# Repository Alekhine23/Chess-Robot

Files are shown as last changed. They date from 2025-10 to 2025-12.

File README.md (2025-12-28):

Chess Engine download:
- Stockfish - (https://stockfishchess.org/download/)

Arduino libraries:
- VarSpeedServo - (https://github.com/netlabtoolkit/VarSpeedServo)
- AccelStepper - (install from Library Manager in Arduino IDE)

Python libraries:
- pip install chess
- pip install pyserial 
- pip install stockfish

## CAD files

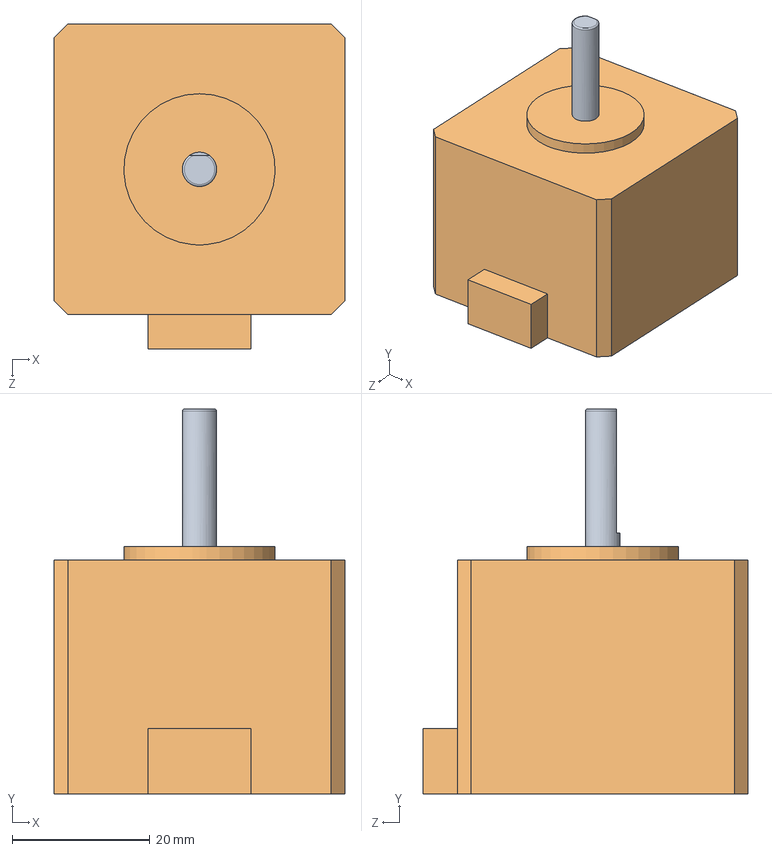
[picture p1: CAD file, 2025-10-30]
Solidworks Model/Steppers/pitch motor/pitch motor.SLDASM
42.3 x 56.0 x 47.3 mm
pitch motor base
pitch motor shaft

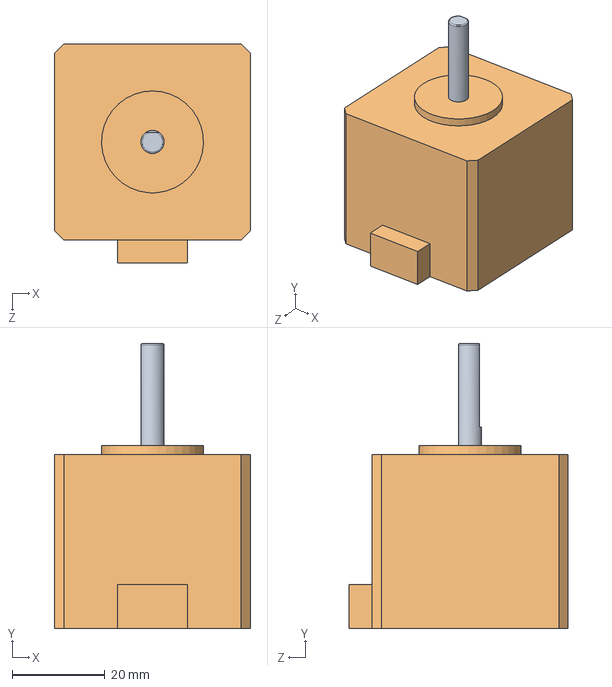
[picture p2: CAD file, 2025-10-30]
Solidworks Model/Steppers/yaw motor/yaw motor.SLDASM
42.3 x 61.5 x 47.3 mm
yaw motor base
yaw motor shaft

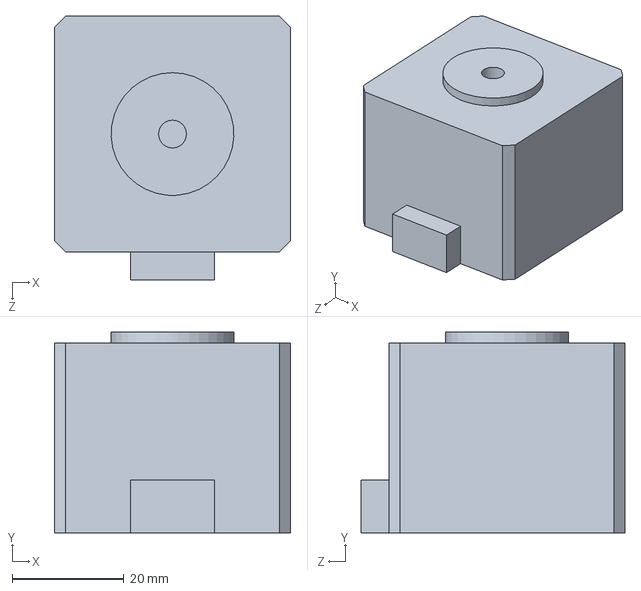
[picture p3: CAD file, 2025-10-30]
Solidworks Model/Steppers/pitch motor/pitch motor base.SLDPRT
42.3 x 36.0 x 47.3 mm

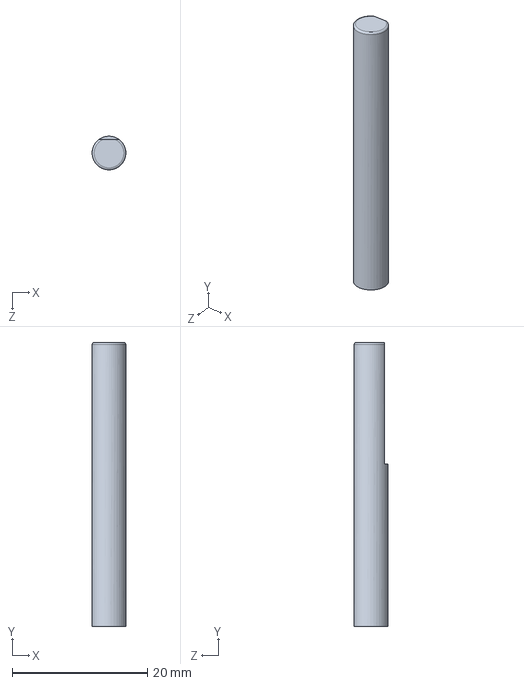
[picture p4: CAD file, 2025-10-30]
Solidworks Model/Steppers/yaw motor/yaw motor shaft.SLDPRT
4.99 x 42.0 x 5.00 mm

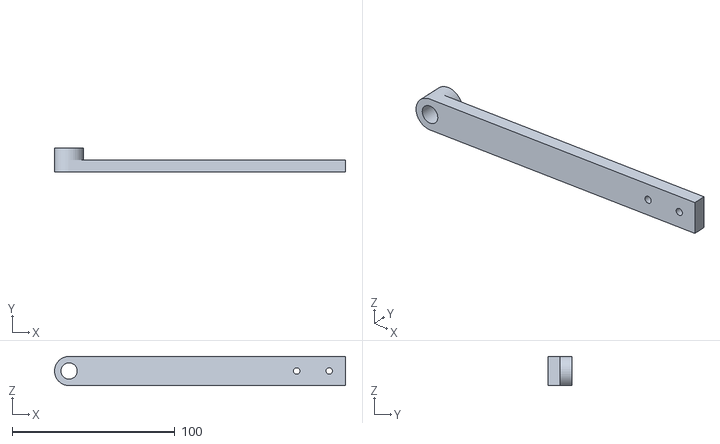
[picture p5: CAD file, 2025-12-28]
STLs and dxfs/elbow wrist link 2B rev1.STL
179.0 x 15.0 x 18.0

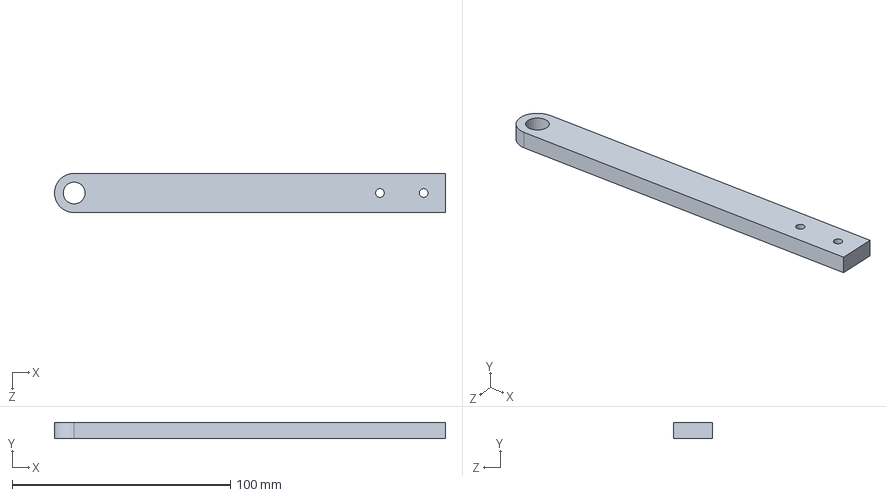
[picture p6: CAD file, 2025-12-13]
Solidworks Model/elbow wrist link 2A rev1.SLDPRT
179.0 x 7.50 x 18.0 mm

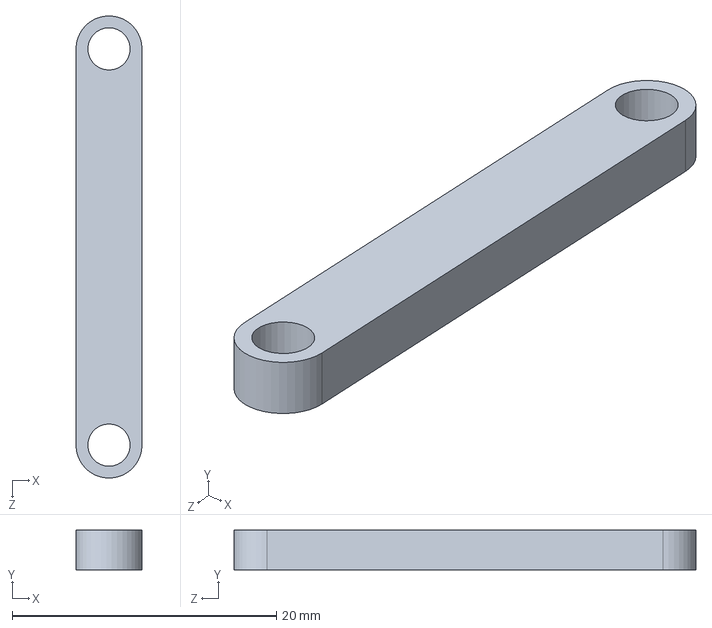
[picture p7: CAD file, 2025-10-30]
Solidworks Model/End Effector/link A.SLDPRT
5.00 x 3.00 x 35.0 mm

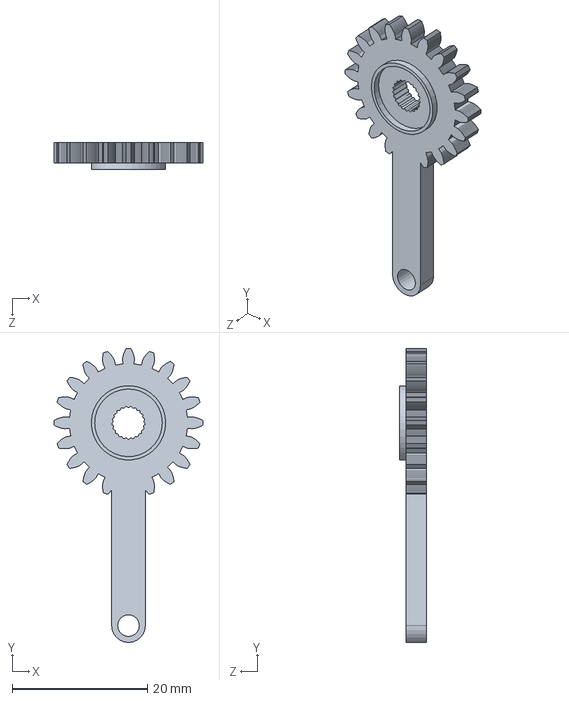
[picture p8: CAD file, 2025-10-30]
Solidworks Model/End Effector/splined grabber.SLDPRT
22.0 x 43.5 x 4.00 mm

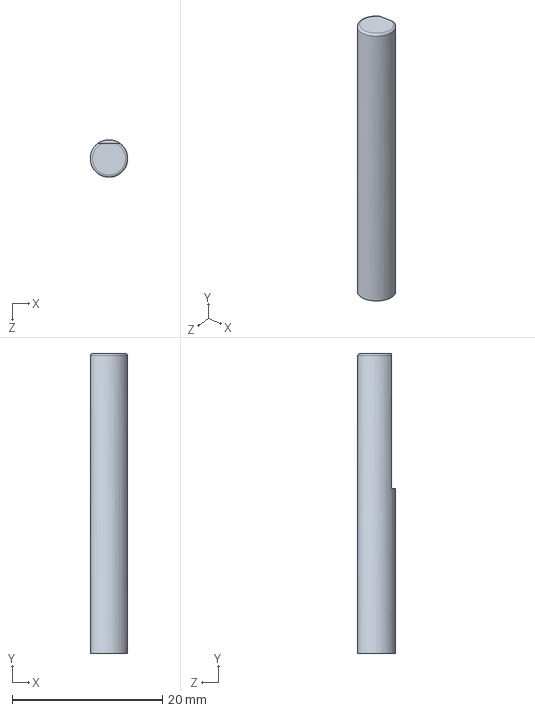
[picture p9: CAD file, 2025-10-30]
Solidworks Model/Steppers/pitch motor/pitch motor shaft.SLDPRT
5.00 x 40.0 x 5.00 mm

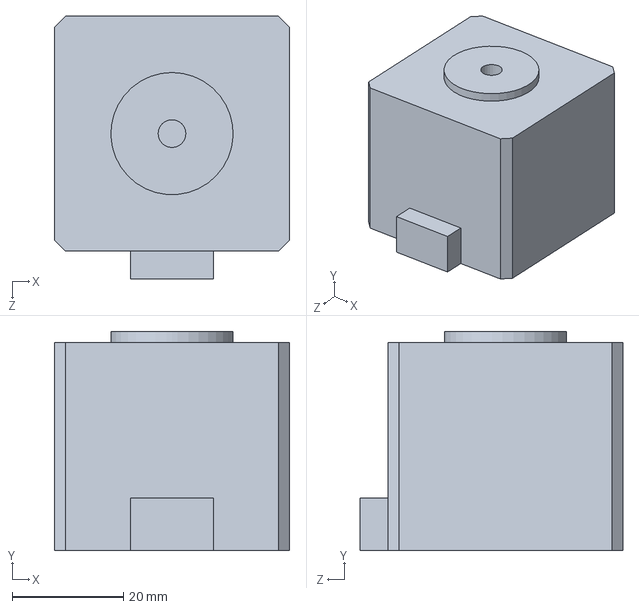
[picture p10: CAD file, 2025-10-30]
Solidworks Model/Steppers/yaw motor/yaw motor base.SLDPRT
42.3 x 39.5 x 47.3 mm

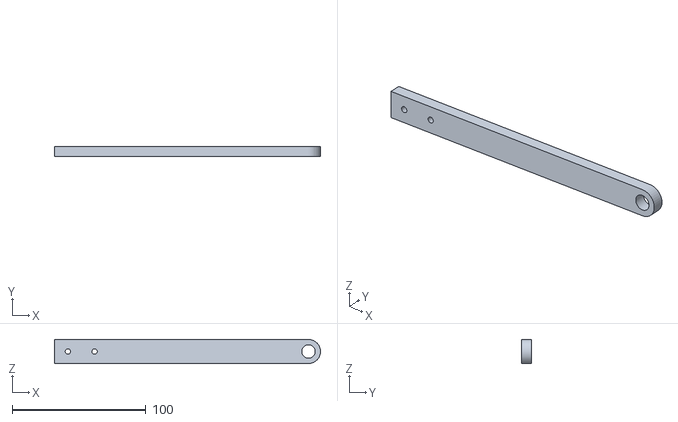
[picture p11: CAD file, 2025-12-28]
STLs and dxfs/elbow wrist link 1A rev1.STL
199.0 x 7.50 x 18.0

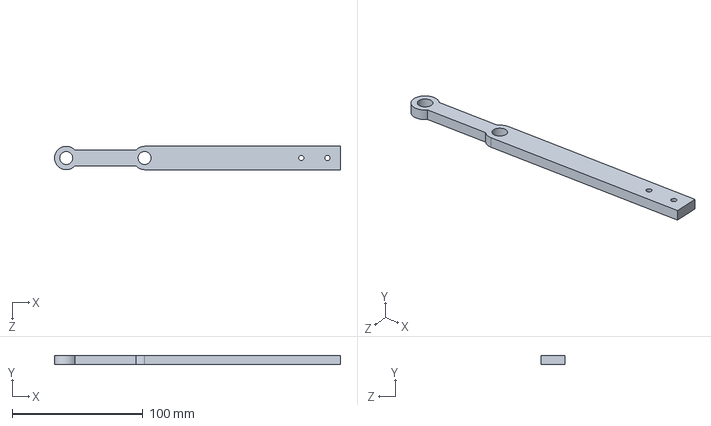
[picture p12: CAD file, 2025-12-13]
Solidworks Model/elbow wrist link 1B rev1.SLDPRT
219.0 x 7.00 x 18.0 mm

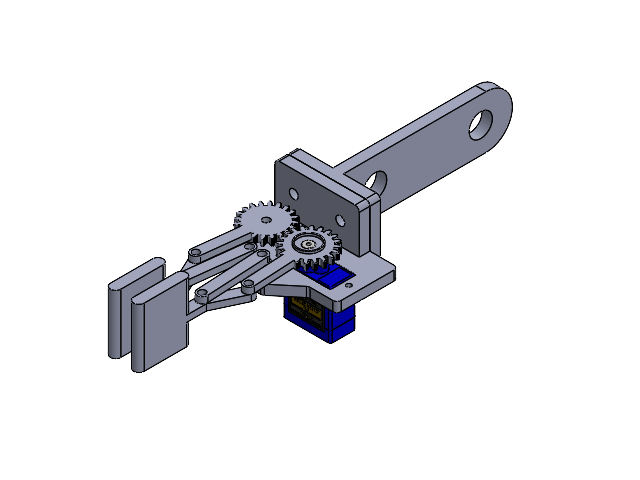
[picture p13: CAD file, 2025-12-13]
Solidworks Model/End Effector/end effector assembly - thicker arm test.SLDASM
chassis
chassis holder
servo motor
splined grabber
unsplined grabber
link A x 2
link B
link C

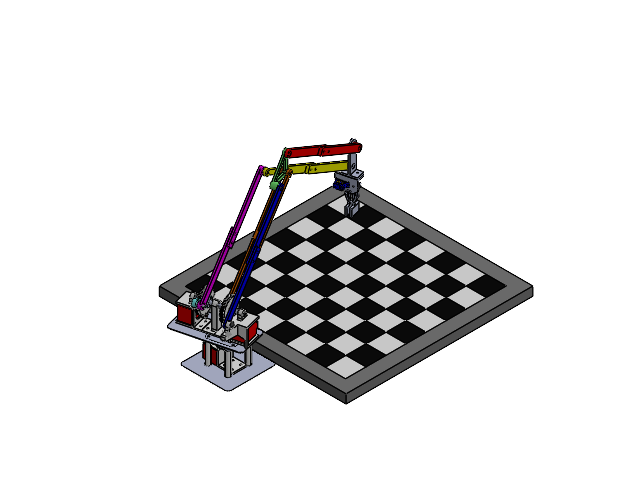
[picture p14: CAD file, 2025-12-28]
Solidworks Model/Full Assembly.SLDASM
bottom base plate
base standoff x 4
yaw motor mount
yaw motor base
yaw motor shaft
yaw motor drive gear
lazy susan bearing x 2
top base plate
pitch motor mount A
pitch motor mount B
shoulder middle axle support
5dia 64 long shaft
5dia 59 long shaft
pitch motor drive gear x 2
pitch motor base x 2
pitch motor shaft x 2
pitch motor driven gear x 2
shoulder axle shaft collar x 4
elbow triangle link
shoulder elbow link 1A x 2
shoulder elbow link 1B x 2
shoulder link 3
shoulder elbow link 4A
shoulder elbow link 4B
5dia 28 long shaft
shoulder elbow link 2A
shoulder elbow link 2B
board
yaw motor driven gear
5dia 15 long shaft x 2
5dia 22.5 long shaft
5dia 25 long shaft
elbow wrist link 1A rev1
elbow wrist link 1B rev1
chassis
chassis holder
servo motor
splined grabber
unsplined grabber
link A x 2
link B
link C
elbow wrist link 2A rev1
elbow wrist link 2B rev1

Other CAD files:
Solidworks Model/End Effector/end effector assembly.SLDASM
STLs and dxfs/elbow wrist link 2A rev1.STL
Solidworks Model/elbow wrist link 2B rev1.SLDPRT
STLs and dxfs/elbow wrist link 1B rev1.STL
STLs and dxfs/base standoff.STL
STLs and dxfs/bottom base plate.DXF
STLs and dxfs/chassis holder.STL
STLs and dxfs/chassis.STL
STLs and dxfs/elbow triangle link.STL
STLs and dxfs/link A.STL
STLs and dxfs/link B.STL
STLs and dxfs/link C.STL
STLs and dxfs/pitch motor drive gear.STL
STLs and dxfs/pitch motor driven gear.STL
STLs and dxfs/pitch motor mount A.STL
STLs and dxfs/pitch motor mount B.STL
STLs and dxfs/shoulder elbow link 1A.STL
STLs and dxfs/shoulder elbow link 1B.STL
STLs and dxfs/shoulder elbow link 2A.STL
STLs and dxfs/shoulder elbow link 2B.STL
STLs and dxfs/shoulder elbow link 4A.STL
STLs and dxfs/shoulder elbow link 4B.STL
STLs and dxfs/shoulder link 3.STL
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

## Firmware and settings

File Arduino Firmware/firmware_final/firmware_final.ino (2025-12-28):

#include <AccelStepper.h>
#include <MultiStepper.h>

#include <VarSpeedServo.h>

const int signal_servo = 12;
const int stepPinRight = 5;
const int dirPinRight = 6;
const int stepPinLeft = 3;
const int dirPinLeft = 4;
const int stepPinBase = 7;
const int dirPinBase = 8;
const int MS1 = 9;
const int MS2 = 10;
const int MS3 = 11;

int command = 0;
int angle;
int speed;
int expectedBytes;

const float degPerStep = 0.9;
int gearRatio = 5;

AccelStepper stepperRight(AccelStepper::DRIVER, stepPinRight, dirPinRight);
AccelStepper stepperLeft(AccelStepper::DRIVER, stepPinLeft, dirPinLeft);
AccelStepper stepperBase(AccelStepper::DRIVER, stepPinBase, dirPinBase);

VarSpeedServo myServo;

void setup() {
  pinMode(stepPinRight, OUTPUT);
  pinMode(dirPinRight, OUTPUT);
  pinMode(stepPinLeft, OUTPUT);
  pinMode(dirPinLeft, OUTPUT);
  pinMode(stepPinBase, OUTPUT);
  pinMode(dirPinBase, OUTPUT);

  pinMode(MS1, OUTPUT);
  pinMode(MS2, OUTPUT);
  pinMode(MS3, OUTPUT);
  digitalWrite(MS1, HIGH);
  digitalWrite(MS2, LOW);
  digitalWrite(MS3, LOW);

  Serial.begin(9600);
  myServo.attach(signal_servo);
  myServo.slowmove(95, 10);
  delay(1000);

  stepperRight.setMaxSpeed(100);
  stepperRight.setAcceleration(100);

  stepperLeft.setMaxSpeed(100);
  stepperLeft.setAcceleration(100);

  stepperBase.setMaxSpeed(100);
  stepperBase.setAcceleration(100);
}

void loop() {
   
  if (Serial.available() > 0) {
    command = Serial.read();

    switch (command) {
      case (1):
        expectedBytes = 2;
        break;
      case (2):
        expectedBytes = 6;
        break;
    }

    unsigned long startTime = millis();
    while (Serial.available() < expectedBytes) {
      if (millis() - startTime > 1000) {
        return;
      }
    }

    switch (command) {
      case (1):
        angle = Serial.read();
        speed = Serial.read();
        myServo.slowmove(angle, speed);

        while(myServo.isMoving()) {
        delay(10);
        }
        delay(100);
        break;

      case (2):
        int angleRight = Serial.read();
        int dirRight = Serial.read();
        int angleLeft = Serial.read();
        int dirLeft = Serial.read();
        int angleBase = Serial.read();
        int dirBase = Serial.read();

        stepperRight.setPinsInverted(dirRight == 0, false, false);
        stepperLeft.setPinsInverted(dirLeft == 0, false, false);
        stepperBase.setPinsInverted(dirBase == 0, false, false);

        int stepsRight = round((angleRight * gearRatio)/degPerStep);
        int stepsLeft = round((angleLeft * gearRatio)/degPerStep);
        int stepsBase = round((angleBase * gearRatio)/degPerStep);

        stepperRight.move(stepsRight);
        stepperLeft.move(stepsLeft);
        stepperBase.move(stepsBase);

        while (stepperRight.distanceToGo() != 0 || stepperLeft.distanceToGo() != 0 || stepperBase.distanceToGo() != 0) {
          stepperRight.run();
          stepperLeft.run();
          stepperBase.run();
          }
        break;
      
      default:
        break;
    }
  }
}

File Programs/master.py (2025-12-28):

from stockfish import Stockfish                 #used to get engine recommended moves
import chess                                    #used for game state tracking (draw, checkmate, captures, etc.)
import math
import serial
import time
import numpy as np

#SERIAL COMMUNICATION
arduino = serial.Serial(port='COM5', baudrate=9600)
time.sleep(2)
arduino.reset_input_buffer()

#CONSTANTS
square_length = 50
margin = 33

y_dist_base_to_board = 70
z_dist_board_to_base = 132.15

arm_length = 300
TCP_to_grab = 104

y_vals = [] #ranks 1 through 8
for i in range(7, -1 , -1):
    y_vals.append(int(margin + i*square_length + square_length/2 + y_dist_base_to_board))

x_vals_half = [] #files a through h
for i in range(3, -1, -1):
    print(i)
    x_vals_half.append(int((i*square_length) + (square_length/2)))
x_vals = x_vals_half
for i in x_vals_half[::-1]:
    x_vals.append(int(-i))

piece_heights = {"pawn": "47.1", "rook": "52.6", "knight": "60.5", "bishop": "68.4", "king": "91.3", "queen": "81.7"}
poised_gripper_heights = {"pawn": 151.1, "rook": 156.6, "knight": 164.5, "bishop": 172.4, "king": 195.3, "queen": 185.7}
close_angles = {"pawn": 95, "rook": 95, "bishop": 95, "knight": 95, "king": 95, "queen": 95}

servo_speed = 10
safe_angle = 95
open_angle = 120

#INITIALIZATION
zero_angles = [0, 0, 0]
capture_angles = [30, 45, 50] #Arbitrary; can dump anywhere on the side, adjust per user setup
position = []
board = chess.Board()

piece_map = {
    chess.PAWN: "pawn",
    chess.ROOK: "rook", 
    chess.KNIGHT: "knight",
    chess.BISHOP: "bishop",
    chess.QUEEN: "queen",
    chess.KING: "king"
}

stockfish = Stockfish(path="/Users/ebabb/Documents/Chess_Robot/stockfish.exe")

#FUNCTIONS
def get_angles(square, piece, is_poised):
    file = int(ord(square[0]) - ord('a'))
    rank = int(square[1]) - 1
    x = x_vals[file]
    y = y_vals[rank]
    if is_poised==0:
        z = float(piece_heights[f"{piece}"]) + TCP_to_grab - z_dist_board_to_base
    else:
        z = float(poised_gripper_heights[f"{piece}"]) + TCP_to_grab - z_dist_board_to_base

    l = math.sqrt(x**2 + y**2)
    phi = math.atan(z/l)*(180/math.pi)
    theta = math.acos(math.sqrt(z**2+l**2)/(2*arm_length))*(180/math.pi)
    a1 = phi+theta
    a2 = phi-theta
    a3 = math.atan(x/y)*(180/math.pi)

    angle_right = 90 - a1
    angle_left = a2
    angle_base = a3

    return [angle_right, angle_left, angle_base]

def get_directions(angles):
    if angles[0] > 0:
        dir_right = 1
    else:
        dir_right = 0
    if angles[1] > 0:
        dir_left = 1
    else:
        dir_left = 0
    if angles[2] > 0:
        dir_base = 1
    else:
        dir_base = 0
    return [dir_right, dir_left, dir_base]

def move_steppers(angle_right, angle_left, angle_base, dir_right, dir_left, dir_base):
    to_send = bytes([
        2,
        abs(int(angle_right)),
        int(dir_right),
        abs(int(angle_left)),
        int(dir_left),
        abs(int(angle_base)),
        int(dir_base)
        ])
    arduino.write(to_send)
    time.sleep(1)

def move_servo(angle):
    to_send = bytes([
        1,
        int(angle),
        int(servo_speed)
        ])
    arduino.write(to_send)
    time.sleep(0.1)

def make_fish_move(move):
    if (move == "O-O") or (move == "O-O-O"):        # Castling sequence
        if move == "O-O":
            king_square1 = "e8"
            king_square2 = "g8"
            rook_square1 = "h8"
            rook_square2 = "f8"
        else:
            king_square1 = "e8"
            king_square2 = "c8"
            rook_square1 = "a8"
            rook_square2 = "d8"
        king_square1_angles = get_angles(king_square1, "king", 0)
        king_square1_angles_poised = get_angles(king_square1, "king", 1)
        king_square2_angles = get_angles(king_square2, "king", 0)
        king_square2_angles_poised = get_angles(king_square2, "king", 1)

        rook_square1_angles = get_angles(rook_square1, "rook", 0)
        rook_square1_angles_poised = get_angles(rook_square1, "rook", 1)
        rook_square2_angles = get_angles(rook_square2, "rook", 0)
        rook_square2_angles_poised = get_angles(rook_square2, "rook", 1)

        angles1 = king_square1_angles_poised
        dirs1 = get_directions(angles1)
        move_steppers(*angles1, *dirs1)

        angles2 = [king_square1_angles[i] - king_square1_angles_poised[i] for i in range(3)]
        dirs2 = get_directions(angles2)
        move_steppers(*angles2, *dirs2)
        move_servo(close_angles["king"])

        angles3 = [king_square1_angles_poised[i] - king_square1_angles[i] for i in range(3)]
        dirs3 = get_directions(angles3)
        move_steppers(*angles3, *dirs3)

        angles4 = [king_square2_angles_poised[i] - king_square1_angles_poised[i] for i in range(3)]
        dirs4 = get_directions(angles4)
        move_steppers(*angles4, *dirs4)

        angles5 = [king_square2_angles[i] - king_square2_angles_poised[i] for i in range(3)]
        dirs5 = get_directions(angles5)
        move_steppers(*angles5, *dirs5)
        move_servo(open_angle)

        angles6 = [king_square2_angles_poised[i] - king_square2_angles[i] for i in range(3)]
        dirs6 = get_directions(angles6)
        move_steppers(*angles6, *dirs6)

        angles7 = [rook_square1_angles_poised[i] - king_square2_angles_poised[i] for i in range(3)]
        dirs7 = get_directions(angles7)
        move_steppers(*angles7, *dirs7)

        angles8 = [rook_square1_angles[i] - rook_square1_angles_poised[i] for i in range(3)]
        dirs8 = get_directions(angles8)
        move_steppers(*angles8, *dirs8)
        move_servo(close_angles["rook"])

        angles9 = [rook_square1_angles_poised[i] - rook_square1_angles[i] for i in range(3)]
        dirs9 = get_directions(angles9)
        move_steppers(*angles9, *dirs9)

        angles10 = [rook_square2_angles_poised[i] - rook_square1_angles_poised[i] for i in range(3)]
        dirs10 = get_directions(angles10)
        move_steppers(*angles10, *dirs10)

        angles11 = [rook_square2_angles[i] - rook_square2_angles_poised[i] for i in range(3)]
        dirs11 = get_directions(angles11)
        move_steppers(*angles11, *dirs11)
        move_servo(open_angle)

        angles12 = [rook_square2_angles_poised[i] - rook_square2_angles[i] for i in range(3)]
        dirs12 = get_directions(angles12)
        move_steppers(*angles12, *dirs12)
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

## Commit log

2025-10-30 added solidworks model and stls
    [5dia 10 long shaft.SLDPRT, 5dia 12.5 long shaft.SLDPRT, 5dia 15 long shaft.SLDPRT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]
2025-10-30 added dxfs
    [Full Assembly.SLDASM, base standoff.STL, bottom base plate.DXF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]
2025-12-13 rewrote firmware more cleanly, added stockfish move vertification
    [Full Assembly - test with thicker arm pieces.SLDASM, elbow wrist link 1A rev1.SLDPRT, elbow wrist link 1B rev1.SLDPRT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]
2025-12-28 added game state recognition, fixed model math errors, final clean up
    [firmware_final.ino, master.py]
2025-12-28 updated arm pieces
    [Full Assembly - test with thicker arm pieces.SLDASM, Full Assembly.SLDASM, elbow wrist link 1A.SLDPRT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]
2025-12-28 added correct arm piece stls
    [elbow wrist link 1A rev1.STL, elbow wrist link 1A.STL, elbow wrist link 1B rev1.STL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]
